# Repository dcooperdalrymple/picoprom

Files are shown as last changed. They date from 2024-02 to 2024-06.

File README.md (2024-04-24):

PicoPROM - DIP-EEPROM Programmer based on Raspberry Pi Pico
===========================================================

Writes ROM images to parallel-interface EEPROMs via XMODEM file transfer over USB.

| Pico and EEPROM connected together | | <a href="http://www.youtube.com/watch?feature=player_embedded&v=Vp6lCNkH-zw" target="_blank">Demo video on YouTube</a> |
|:----:|----|:----:|
| Pico connected to EEPROM | | Demo video on YouTube |

Warning
-------
The Raspberry Pi Pico is not 5V-tolerant, but these EEPROMs are 5V devices.
This is fine for write-only access, but it's important to ensure the EEPROM
never writes back to the Pico's GPIO pins.  **Make sure OE is permanently wired
high, to VCC, to prevent this.**

Features
--------

* No additional components are required - just the Pico and the EEPROM
* XMODEM+CRC transfer protocol makes it easy to send files to be written to the EEPROM
* Fast operation - comparable to TL866
* Supports paged writes as well as byte-writes
* Supports write protection

Not features
------------
* Reading back and verifying is not supported and probably won't ever be
* YMODEM, ZMODEM, and other XMODEM extensions aren't supported yet

Binary Installation
-------------------
1. Without an EEPROM connected, hold BOOTSEL and connect the Raspberry Pi Pico
2. Drag picoprom.uf2 into the Raspberry Pi Pico's mass storage window
3. It should then reboot and start communicating over USB Serial

Usage
-----
1. Disconnect the Raspberry Pi Pico from power/USB
2. Wire the Raspberry Pi Pico up to the EEPROM according to the pinout table below
3. Connect the Raspberry Pi Pico to the computer by USB
4. Launch a terminal app with XMODEM support, such as Tera Term, and connect it to the Raspberry Pi Pico
5. Verify that the Raspberry Pi Pico is reporting that it's ready to receive a ROM image
7. Use your terminal to send a ROM image using the XMODEM+CRC protocol
8. Disconnect power before removing the EEPROM from the circuit

Alternatively, instead of starting the XMODEM transfer, press Enter for some configuration options and follow the instructions.

Pinout
------
The pinout is quite straightforward - the pins are laid out around the Pico in almost 
the same arrangement that they appear on the EEPROM, to make it easy and tidy to wire up.

**Make sure OE is connected high, to VCC, as allowing it to float low could cause damage to your Pico.**

| Pico pin | EEPROM pin | Function | | Pico pin | EEPROM pin | Function |
| --- |:---:| --- | ---- | --- |:---:| --- |
| GP3 | 1  | A14 | | VSYS | 28 | VCC |
| GP4 | 2  | A12 | | GND | 27 | WE |
| GP5 | 3  | A7 | | GP2 | 26 | A13 |
| GP6 | 4  | A6 | | GP28 | 25 | A8 |
| GP7 | 5  | A5 | | GP27 | 24 | A9 |
| GP8 | 6  | A4 | | GP26 | 23 | A11 |
| GP9 | 7  | A3 | | VSYS | 22 | OE |
| GP10 | 8  | A2 | | GP22 | 21 | A10 |
| GP11 | 9  | A1 | | GP21 | 20 | CE |
| GP12 | 10 | A0 | | GP20 | 19 | D7 |
| GP13 | 11 | D0 | | GP19 | 18 | D6 |
| GP14 | 12 | D1 | | GP18 | 17 | D5 |
| GP15 | 13 | D2 | | GP17 | 16 | D4 |
| GND | 14 | GND | | GP16 | 15 | D3 |

### Other options

Depending upon preference, you could swap the CE and WE connections, or connect
them both to GP21.  It doesn't make any difference to the programming
operation, I just chose this layout because it seemed most convenient to me.

If you go further and change the GP pin numbering then you'll need to update
the corresponding array in `picoprom.c`.

Cloning and Building from Source
--------------------------------
1. Set up `pico-sdk` according to the Pico's getting-started guide.
2. Clone this repository alongside `pico-sdk`
3. Create a `build` folder
4. From within the `build` folder, type: `cmake ..`
5. From within the `build` folder, type: `make`

ROM Verification Support
------------------------

In order to verify EEPROM contents after writing, an octal bus transceiver
such as the 74HC245 must be used on the data bus between the Pico and the EEPROM.
The output enable and write enable pins must also be connected to GP0 and GP1 respectively.
The direction of this transceiver is controlled by the OE pin. Please refer to the
[included schematic](hardware/assets/schematic.pdf) for appropriate wiring.

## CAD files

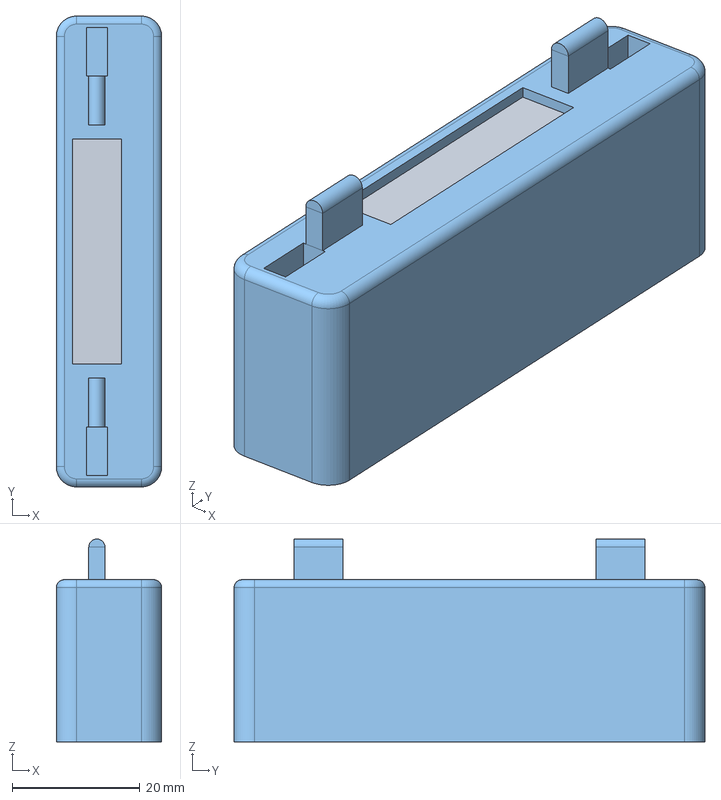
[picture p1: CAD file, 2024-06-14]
adapters/atari2600/case/picoprom-atari2600.FCStd
16.5 x 73.7 x 31.8 mm
EdgeConnector
PinHeader
CartridgeAdapter

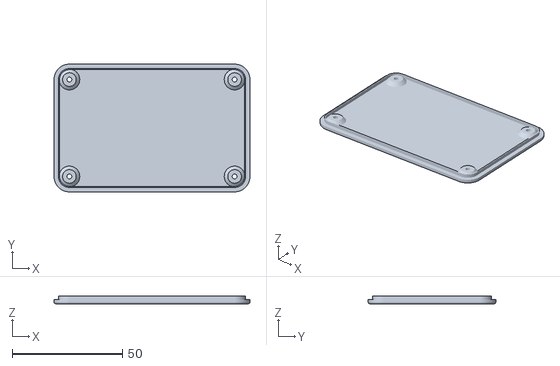
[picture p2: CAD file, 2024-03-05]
case/bottom.stl
89.0 x 58.0 x 3.60

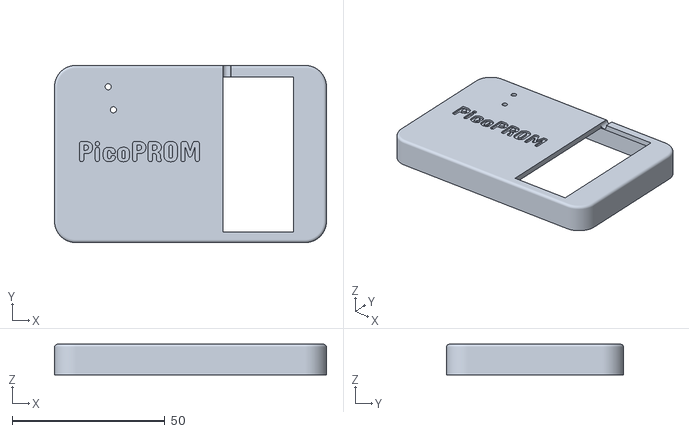
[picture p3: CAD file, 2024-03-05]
case/top.stl
89.0 x 58.0 x 10.0

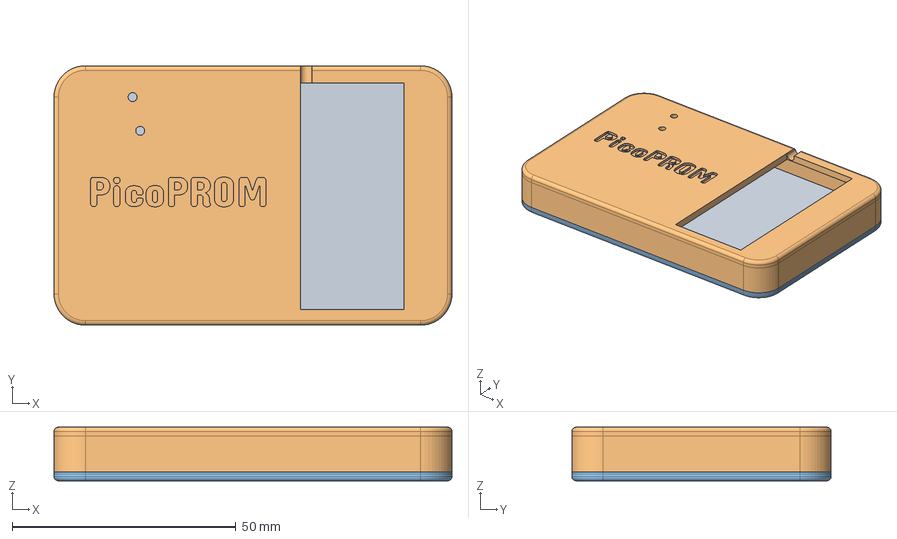
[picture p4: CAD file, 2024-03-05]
case/picoprom.FCStd
89.0 x 58.0 x 12.0 mm
PCB
TopRounded
BottomRounded

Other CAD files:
adapters/atari2600/case/picoprom-atari2600.stl

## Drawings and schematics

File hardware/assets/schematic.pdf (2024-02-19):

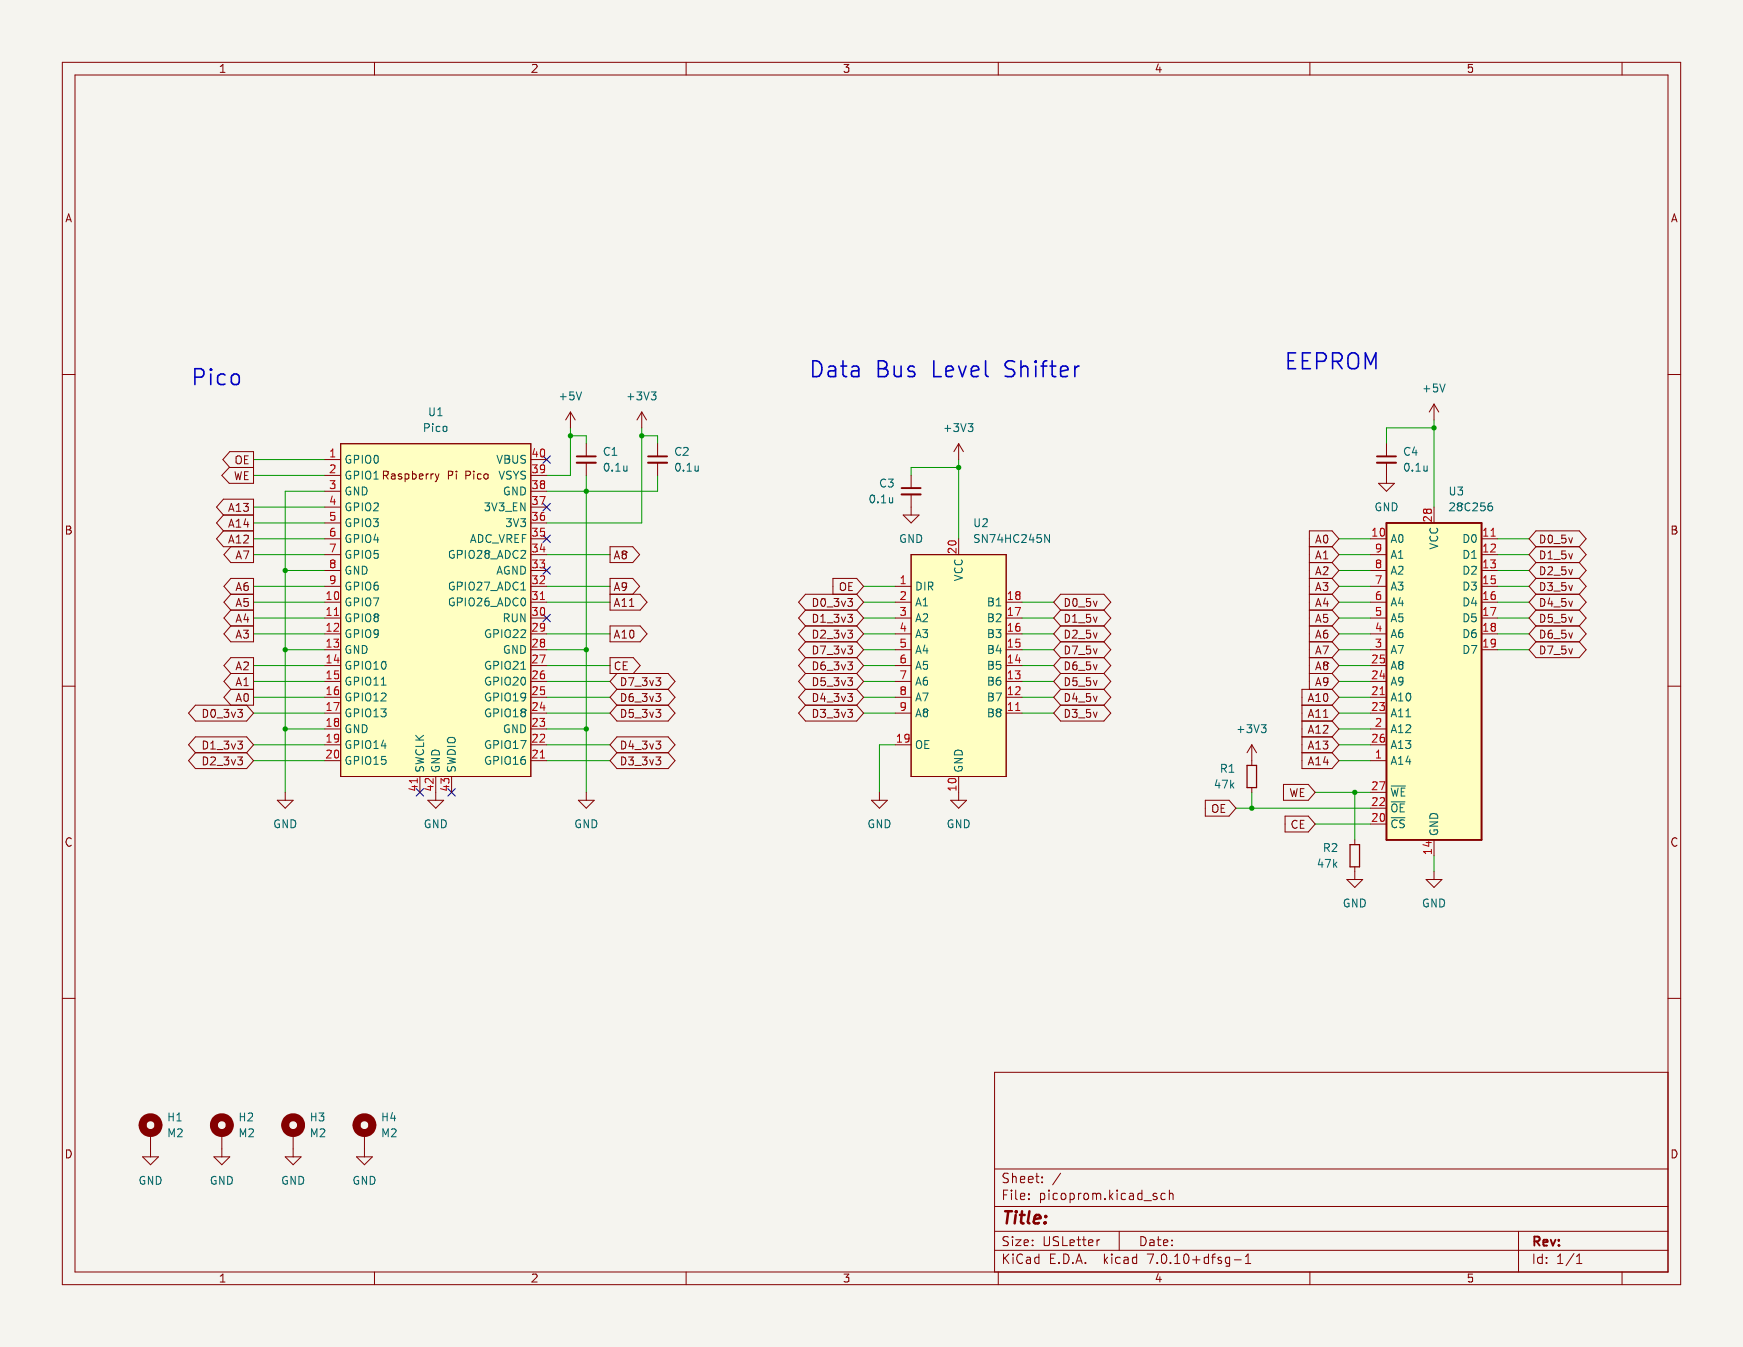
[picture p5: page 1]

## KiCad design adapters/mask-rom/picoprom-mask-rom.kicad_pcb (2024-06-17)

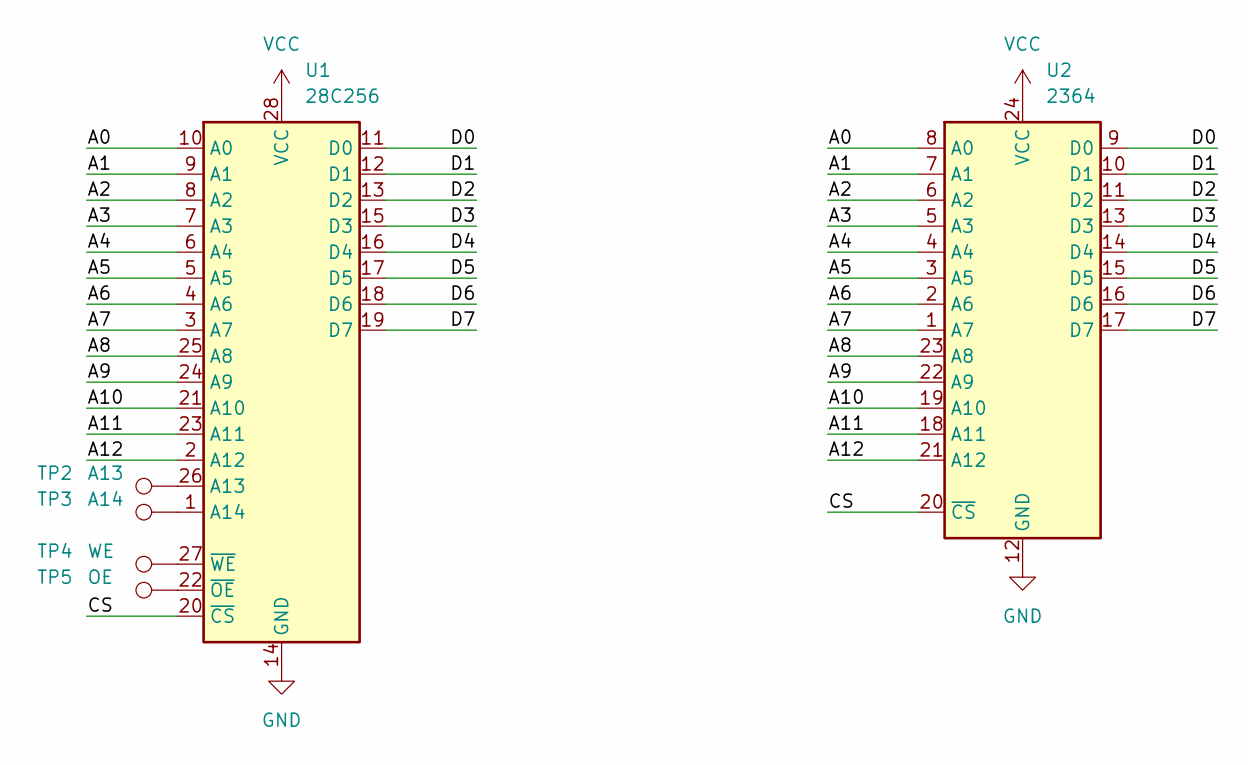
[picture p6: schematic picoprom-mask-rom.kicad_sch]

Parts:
TP2: A13; TestPoint_Pad_D1.0mm
TP3: A14; TestPoint_Pad_D1.0mm
TP4: WE; TestPoint_Pad_D1.0mm
TP5: OE; TestPoint_Pad_D1.0mm
U1: 28C256; PicoPROM_DIP-28_W15.24mm
U2: 2364; DIP-24_W15.24mm_Socket

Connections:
/A0: U1.10 (A0), U2.8 (A0)
/A1: U1.9 (A1), U2.7 (A1)
/A2: U1.8 (A2), U2.6 (A2)
/A3: U1.7 (A3), U2.5 (A3)
/A4: U1.6 (A4), U2.4 (A4)
/A5: U1.5 (A5), U2.3 (A5)
/A6: U1.4 (A6), U2.2 (A6)
/A7: U1.3 (A7), U2.1 (A7)
/A8: U1.25 (A8), U2.23 (A8)
/A9: U1.24 (A9), U2.22 (A9)
/A10: U1.21 (A10), U2.19 (A10)
/A11: U1.23 (A11), U2.18 (A11)
/A12: U1.2 (A12), U2.21 (A12)
/CS: U1.20 (~CS), U2.20 (~CS)
/D0: U1.11 (D0), U2.9 (D0)
/D1: U1.12 (D1), U2.10 (D1)
/D2: U1.13 (D2), U2.11 (D2)
/D3: U1.15 (D3), U2.13 (D3)
/D4: U1.16 (D4), U2.14 (D4)
/D5: U1.17 (D5), U2.15 (D5)
/D6: U1.18 (D6), U2.16 (D6)
/D7: U1.19 (D7), U2.17 (D7)
GND: U1.14 (GND), U2.12 (GND)
unnamed: TP2.1, U1.26 (A13)
unnamed: TP3.1, U1.1 (A14)
unnamed: TP5.1, U1.22 (~OE)
unnamed: TP4.1, U1.27 (~WE)
VCC: U1.28 (VCC), U2.24 (VCC)

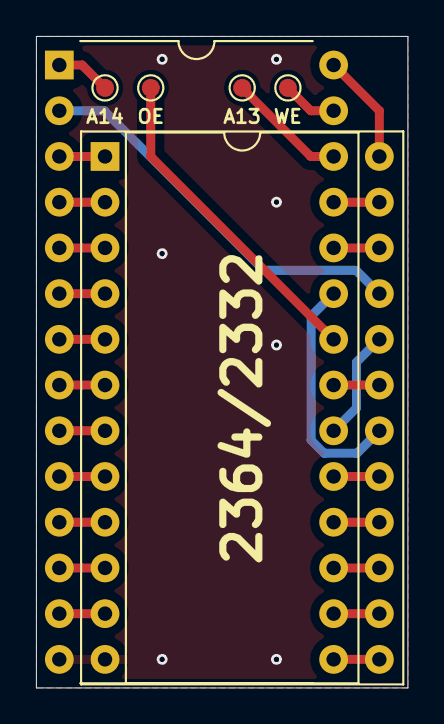
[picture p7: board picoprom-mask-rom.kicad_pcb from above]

Board: 2 copper layers, 20.6 x 36.2 mm, 6 parts (0 on the bottom side), 28 nets.

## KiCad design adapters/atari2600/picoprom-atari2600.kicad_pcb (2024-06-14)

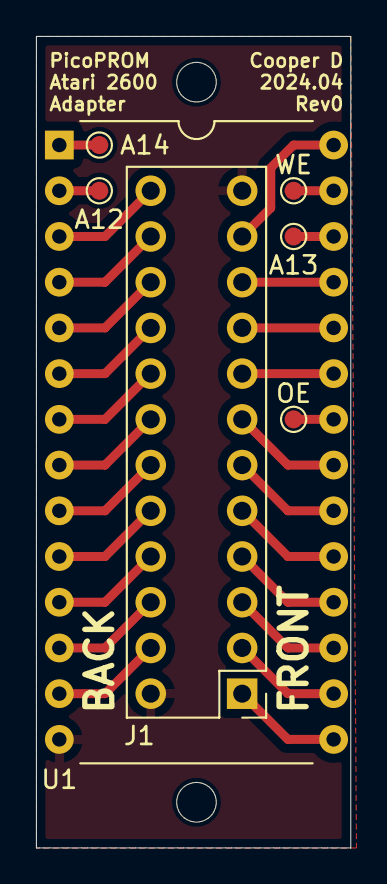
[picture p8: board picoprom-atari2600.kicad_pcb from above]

Board: 2 copper layers, 17.5 x 45.1 mm, 7 parts (0 on the bottom side), 28 nets.

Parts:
A12: A12; TestPoint_Pad_D1.0mm
A13: A13; TestPoint_Pad_D1.0mm
A14: A14; TestPoint_Pad_D1.0mm
J1: Atari2600_Cartridge_Edge; EdgeConnector_2x12_P2.54mm_Vertical
OE: OE; TestPoint_Pad_D1.0mm
U1: 28C256; PicoPROM_DIP-28_W15.24mm
WE: WE; TestPoint_Pad_D1.0mm

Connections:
/A0: J1.20, U1.10 (A0)
/A1: J1.19, U1.9 (A1)
/A2: J1.18, U1.8 (A2)
/A3: J1.17, U1.7 (A3)
/A4: J1.16, U1.6 (A4)
/A5: J1.15, U1.5 (A5)
/A6: J1.14, U1.4 (A6)
/A7: J1.13, U1.3 (A7)
/A8: J1.10, U1.25 (A8)
/A9: J1.9, U1.24 (A9)
/A10: J1.7, U1.21 (A10)
/A11: J1.8, U1.23 (A11)
/CS: J1.6, U1.20 (~CS)
/D0: J1.21, U1.11 (D0)
/D1: J1.22, U1.12 (D1)
/D2: J1.23, U1.13 (D2)
/D3: J1.1, U1.15 (D3)
/D4: J1.2, U1.16 (D4)
/D5: J1.3, U1.17 (D5)
/D6: J1.4, U1.18 (D6)
/D7: J1.5, U1.19 (D7)
GND: J1.12, J1.24, U1.14 (GND)
unnamed: A12.1, U1.2 (A12)
unnamed: A13.1, U1.26 (A13)
unnamed: A14.1, U1.1 (A14)
unnamed: OE.1, U1.22 (~OE)
unnamed: U1.27 (~WE), WE.1
VCC: J1.11, U1.28 (VCC)

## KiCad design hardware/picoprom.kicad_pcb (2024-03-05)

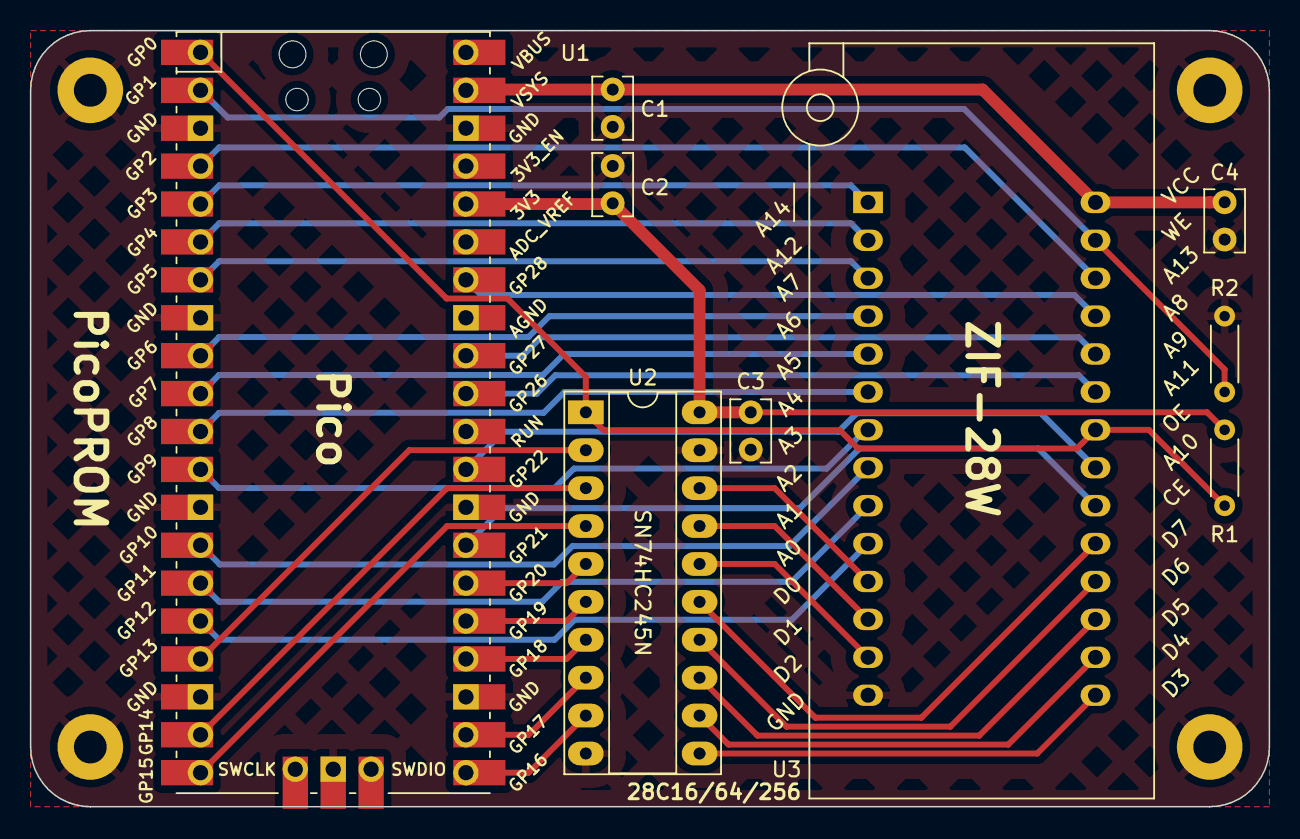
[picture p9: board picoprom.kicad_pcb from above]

Board: 2 copper layers, 83.0 x 52.0 mm, 13 parts (0 on the bottom side), 37 nets.

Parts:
C1, C2, C3, C4: 0.1uF; C_Rect_L4.0mm_W2.5mm_P2.50mm
H1, H2, H3, H4: M2; MountingHole_2.2mm_M2_Pad
R1, R2: 47k; R_Axial_DIN0204_L3.6mm_D1.6mm_P5.08mm_Horizontal
U1: Pico; RPi_Pico_SMD_TH
U2: SN74HC245N; DIP-20_W7.62mm_Socket_LongPads
U3: 28C256; DIP_Socket-28_W11.9_W12.7_W15.24_W17.78_W18.5_3M_228-1277-0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

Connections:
+3V3: C2.1, C3.1, R1.1, U1.36 (3V3), U2.20 (VCC)
+5V: C1.1, C4.1, U1.39 (VSYS), U3.28 (VCC)
A0: U1.16 (GPIO12), U3.10 (A0)
A1: U1.15 (GPIO11), U3.9 (A1)
A2: U1.14 (GPIO10), U3.8 (A2)
A3: U1.12 (GPIO9), U3.7 (A3)
A4: U1.11 (GPIO8), U3.6 (A4)
A5: U1.10 (GPIO7), U3.5 (A5)
A6: U1.9 (GPIO6), U3.4 (A6)
A7: U1.7 (GPIO5), U3.3 (A7)
A8: U1.34 (GPIO28_ADC2), U3.25 (A8)
A9: U1.32 (GPIO27_ADC1), U3.24 (A9)
A10: U1.29 (GPIO22), U3.21 (A10)
A11: U1.31 (GPIO26_ADC0), U3.23 (A11)
A12: U1.6 (GPIO4), U3.2 (A12)
A13: U1.4 (GPIO2), U3.26 (A13)
A14: U1.5 (GPIO3), U3.1 (A14)
CE: U1.27 (GPIO21), U3.20 (~CS)
D0_3v3: U1.17 (GPIO13), U2.2 (A1)
D0_5v: U2.18 (B1), U3.11 (D0)
D1_3v3: U1.19 (GPIO14), U2.3 (A2)
D1_5v: U2.17 (B2), U3.12 (D1)
D2_3v3: U1.20 (GPIO15), U2.4 (A3)
D2_5v: U2.16 (B3), U3.13 (D2)
D3_3v3: U1.21 (GPIO16), U2.9 (A8)
D3_5v: U2.11 (B8), U3.15 (D3)
D4_3v3: U1.22 (GPIO17), U2.8 (A7)
D4_5v: U2.12 (B7), U3.16 (D4)
D5_3v3: U1.24 (GPIO18), U2.7 (A6)
D5_5v: U2.13 (B6), U3.17 (D5)
D6_3v3: U1.25 (GPIO19), U2.6 (A5)
D6_5v: U2.14 (B5), U3.18 (D6)
D7_3v3: U1.26 (GPIO20), U2.5 (A4)
D7_5v: U2.15 (B4), U3.19 (D7)
GND: C1.2, C2.2, C3.2, C4.2, H1.1, H2.1, H3.1, H4.1, R2.2, U1.3 (GND), U1.8 (GND), U1.13 (GND), U1.18 (GND), U1.23 (GND), U1.28 (GND), U1.38 (GND), U1.42 (GND), U2.10 (GND), U2.19 (OE), U3.14 (GND)
OE: R1.2, U1.1 (GPIO0), U2.1 (DIR), U3.22 (~OE)
WE: R2.1, U1.2 (GPIO1), U3.27 (~WE)

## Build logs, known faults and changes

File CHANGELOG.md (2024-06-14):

# Changelog

## [0.24] 2024-06-14
### Added
- File transfer & upload actions
- Atari 2600 cartridge reader adapter 3d printed connector
- Address mask in device configuration settings
- Added 2364/2332 mask ROM device configurations
- Mask ROM adapter pcb

### Changed
- Global file selection routines
- Global file name prompt routine
- Default to fetch Pico SDK from git

### Fixed
- Added post-delay to XMODEM transfers
- Error checking during image write process

## [0.23] 2024-04-24
### Added
- Atari 2600 cartridge reader adapter pcb
- Tool menu with specialized write and verification commands
- Local flash filesystem to store and retrieve ROM images (littlefs)

### Changed
- XMODEM communication moved into submodule
- Menu & device systems rewritten and project reorganized
- Assume full data reading/writing hardware capabilities

## [0.22] 2024-03-27
### Added
- Hardware PCB design
- 3D printed case
- ROM read/verification
- XMODEM send
- Page read

### Changed
- Menu items for image and page read

### Fixed
- Disable automatic carriage return
- Prompt typos
- Ignore backspaces and NAKs when inappropriate
- Increased EOT timeout
- Improved verbosity

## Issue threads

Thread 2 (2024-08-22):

Why the SN74HC245N is needed to read the ROM?

odelot, 2024-08-22:
Hi,

nice video and fork you have here ;-)

I was confused why the SN74HC245N is needed to read the rom? Can you tell me why? (I really do not know. I was trying to read direct and I coudn't, and I cannot understand why since PICO GPIOs are 5v tolerants)

I thought it was just change the data pins from output to input, but it seems this do not work.

Thanks in advance,

Fábio

relic-se, 2024-11-18:
Sorry for the delay in responding to your issue. Although many Pico users have had success using 5V logic directly with GPIO without the use of level shifters, it is technically out of spec with the MCU's capabilities and not recommended for long-term deployments. If you are temporarily experimenting with this project, it is likely okay to test EEPROM reading capabilities directly with the GPIO of the RP2040, but don't take that as a recommendation in any way and you do run the risk of damaging your device. Most projects similar to this one (ie: RP2040-based rom carts, vintage computer peripherals, etc) utilize 5V level shifters for the same reasons.

5V TTL logic on the other hand is tolerant to 3.3V input. This is why the control signals are handled directly by the RP2040's GPIO and only the data bus requires a level shifter.

Closed 2024-11-18.

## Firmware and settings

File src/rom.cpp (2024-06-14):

#include "rom.hpp"

#include "pico/rand.h"

static const uint LED_PIN = 25;

static const uint ADDR_MAP[] = { // A0-14
    12, 11, 10, 9, 8, 7, 6, 5, 28, 27, 22, 26, 4, 2 ,3
};

static const uint DATA_MAP[] = { // D0-7
    13, 14, 15, 16, 17, 18, 19, 20
};

static const uint CE_PIN = 21;
static const uint OE_PIN = 0;
static const uint WE_PIN = 1;

ROM::ROM(rom_config_t config) {
    this->config = config;

    gpio_init(LED_PIN);
	gpio_set_dir(LED_PIN, true);
	gpio_put(LED_PIN, true);

    for (uint8_t i = 0; i < sizeof(ADDR_MAP) / sizeof(*ADDR_MAP); i++) {
        gpio_init(ADDR_MAP[i]);
        gpio_set_dir(ADDR_MAP[i], true);
    }
    this->set_address(this->config.addressMask);

    for (uint8_t i = 0; i < sizeof(DATA_MAP) / sizeof(*DATA_MAP); i++) {
        gpio_init(DATA_MAP[i]);
        gpio_set_dir(DATA_MAP[i], false);
    }

    gpio_init(CE_PIN);
	gpio_set_dir(CE_PIN, true);
	gpio_put(CE_PIN, !this->config.invertClock);

    if (!this->config.readonly) {
        gpio_init(OE_PIN);
        gpio_set_dir(OE_PIN, true);
        gpio_put(OE_PIN, true);

        gpio_init(WE_PIN);
        gpio_set_dir(WE_PIN, true);
        gpio_put(WE_PIN, true);
    }
};

ROM::~ROM() {
    gpio_put(LED_PIN, false);
    gpio_deinit(LED_PIN);

    this->set_address(0);
    for (uint8_t i = 0; i < sizeof(ADDR_MAP) / sizeof(*ADDR_MAP); i++) {
        gpio_deinit(ADDR_MAP[i]);
    }

    for (uint8_t i = 0; i < sizeof(DATA_MAP) / sizeof(*DATA_MAP); i++) {
        gpio_deinit(DATA_MAP[i]);
    }

    gpio_put(CE_PIN, false);
    gpio_deinit(CE_PIN);

    if (!this->config.readonly) {
        gpio_put(OE_PIN, false);
        gpio_deinit(OE_PIN);

        gpio_put(WE_PIN, false);
        gpio_deinit(WE_PIN);
    }
};

const rom_config_t * ROM::get_config() const {
    return &this->config;
};

size_t ROM::get_size() const {
    return this->config.size;
};

size_t ROM::get_page_size() const {
    return this->config.pageSize;
};

bool ROM::read(uint8_t * data, size_t size, size_t offset, bool print_status) {
    if (offset > this->config.size) return false;
    if (!size) size = this->config.size;
    if (size > this->config.size - offset) size = this->config.size - offset;

    for (size_t address = offset; address < offset + size; address++) {
        data[address - offset] = this->read_byte(address);
        this->status(address, print_status);
    }
    return true;
};
bool ROM::read(uint8_t * data, size_t size, size_t offset) {
    return this->read(data, size, offset, true);
};
bool ROM::read(uint8_t * data, size_t size) {
    return this->read(data, size, 0, true);
};
bool ROM::read(uint8_t * data) {
    return this->read(data, this->config.size, 0, true);
};

const static uint8_t * _data_image;
uint8_t data_image(size_t address) {
    return _data_image[address];
};

static uint8_t _data_value = 0;
uint8_t data_value(size_t address) {
    return _data_value;
};

uint8_t data_random(size_t address) {
    return (uint8_t)(get_rand_32() & 0xff);
};

uint8_t data_index(size_t address) {
    return (uint8_t)(address & 0xff);
};

bool ROM::write_image(const uint8_t * data, size_t size, size_t offset, bool print_status) {
    _data_image = data;
    return this->write(data_image, size, offset, print_status);
};
bool ROM::write_image(const uint8_t * data, size_t size, size_t offset) {
    return this->write_image(data, size, offset, true);
};
bool ROM::write_image(const uint8_t * data, size_t size) {
    return this->write_image(data, size, 0, true);
};

bool ROM::write_value(uint8_t value, bool print_status) {
    _data_value = value;
    return this->write(data_value, this->config.size, 0, print_status);
};
bool ROM::write_value(uint8_t value) {
    return this->write_value(value, true);
};

bool ROM::write_random(bool print_status) {
    return this->write(data_random, this->config.size, 0, print_status);
};
bool ROM::write_random() {
    return this->write_random(true);
};

bool ROM::write_index(bool print_status) {
    return this->write(data_index, this->config.size, 0, print_status);
};
bool ROM::write_index() {
    return this->write_index(true);
};

bool ROM::write(data_func_t cb, size_t size, size_t offset, bool print_status) {
    if (this->config.readonly || size + offset > this->config.size) return false;
    if (this->config.writeProtectDisable) {
        this->write_byte(0x5555, 0xAA);
        this->write_byte(0x2AAA, 0x55);
        this->write_byte(0x5555, 0x80);
        this->write_byte(0x5555, 0xAA);
        this->write_byte(0x2AAA, 0x55);
        this->write_byte(0x5555, 0x20);
        if (this->config.pageDelayMs) sleep_ms(this->config.pageDelayMs);
    }
    for (size_t address = offset; address < offset + size; address++) {
        if (this->config.pageSize && (address % this->config.pageSize) == 0) {
            if (this->config.pageDelayMs) sleep_ms(this->config.pageDelayMs);
            if (this->config.writeProtect) {
                // Locking prefix
                this->write_byte(0x5555, 0xAA);
                this->write_byte(0x2AAA, 0x55);
                this->write_byte(0x5555, 0xA0);
            }
        }
        this->write_byte(address, cb(address - offset));
        this->status(address, print_status);
    }
    if (this->config.pageDelayMs) sleep_ms(this->config.pageDelayMs);
    return true;
};

size_t ROM::verify_image(uint8_t * data, size_t size, size_t offset, bool print_status) {
    _data_image = data;
    return this->verify(data_image, size, offset, print_status);
};
size_t ROM::verify_image(uint8_t * data, size_t size, size_t offset) {
    return this->verify_image(data, size, offset, true);
};
size_t ROM::verify_image(uint8_t * data, size_t size) {
    return this->verify_image(data, size, 0, true);
};

size_t ROM::verify_value(uint8_t value, bool print_status) {
    _data_value = value;
    return this->verify(data_value, this->config.size, 0, print_status);
};
size_t ROM::verify_value(uint8_t value) {
    return this->verify_value(value, true);
};

size_t ROM::verify_index(bool print_status) {
    return this->verify(data_index, this->config.size, 0, print_status);
};
size_t ROM::verify_index() {
    return this->verify_index(true);
};

size_t ROM::verify(data_func_t cb, size_t size, size_t offset, bool print_status) {
    if (size + offset > this->config.size) return -1;
    size_t error = 0;
    for (size_t address = offset; address < offset + size; address++) {
        if (this->read_byte(address) != cb(address - offset)) error += 1;
        this->status(address, print_status);
    }
    return error;
};

void ROM::print() {
    this->config.print();
};

void ROM::status(size_t address, bool output) {
    gpio_put(LED_PIN, (address & 0x100) != 0);
    if (output && ((address + 1) & 0x7FF) == 0) printf("%dK ", (address + 1) >> 10);
};
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

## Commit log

2024-02-16 Initial hardware design.
    [picoprom.kicad_pcb, picoprom.kicad_sch]
2024-02-19 Final edits to hardware for Rev0.
    [picoprom.kicad_pcb, picoprom.kicad_sch]
2024-03-05 Added 3d printed case.
    [bottom.stl, picoprom.FCStd, picoprom.kicad_pcb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]
2024-03-27 Disable automatic carriage return.
2024-04-03 Atari 2600 cartridge reader adapter.
    [picoprom-atari2600.kicad_pcb, picoprom-atari2600.kicad_sch]
2024-04-24 Added pico-filesystem submodule
2024-04-24 Switched over to using littlefs directly and fixed a number of bugs.
2024-04-25 Change device selection name.
2024-05-02 3d-printed cartridge connector for Atari 2600 adapter.
    [picoprom-atari2600.FCStd, picoprom-atari2600.kicad_pcb, picoprom-atari2600.stl]
2024-05-02 Default to fetch Pico SDK from git.
2024-06-14 Allow device configuration to set address mask. Useful for setting upper gpio high for specific device adapters.
2024-06-14 2364/2332 Mask ROM support with passive adapter.
    [picoprom-mask-rom.kicad_pcb, picoprom-mask-rom.kicad_sch]
2024-06-17 Add KiCAD preview using KiCanvas.
    [picoprom-mask-rom.kicad_pcb]
